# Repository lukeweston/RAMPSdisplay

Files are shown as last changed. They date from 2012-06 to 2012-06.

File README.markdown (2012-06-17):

v1.1: No SD card or thermocouples. Very simple, low-density, "agricultural" PCB layout, which can easily be made single-sided and is well suited to DIY PCB fabrication. Even inexperienced persons should be able to easily make a working board, using photolithography, toner transfer, or CNC milling techniques.

v1.2: "Official" production version. Includes three thermocouple interfaces and micro-SD card. Micro-SD card socket is the Amphenol 101-00660-68-6.

v1.3: Changed to the same micro-SD card PCB footprint as the Kliment SDRamps board, using some generic micro-SD card socket from eBay.
Also changed to self-oscillating through-hole buzzer, removed buzzer drive oscillator, and reduced prototyping hole number to keep total drill hits less than 300.

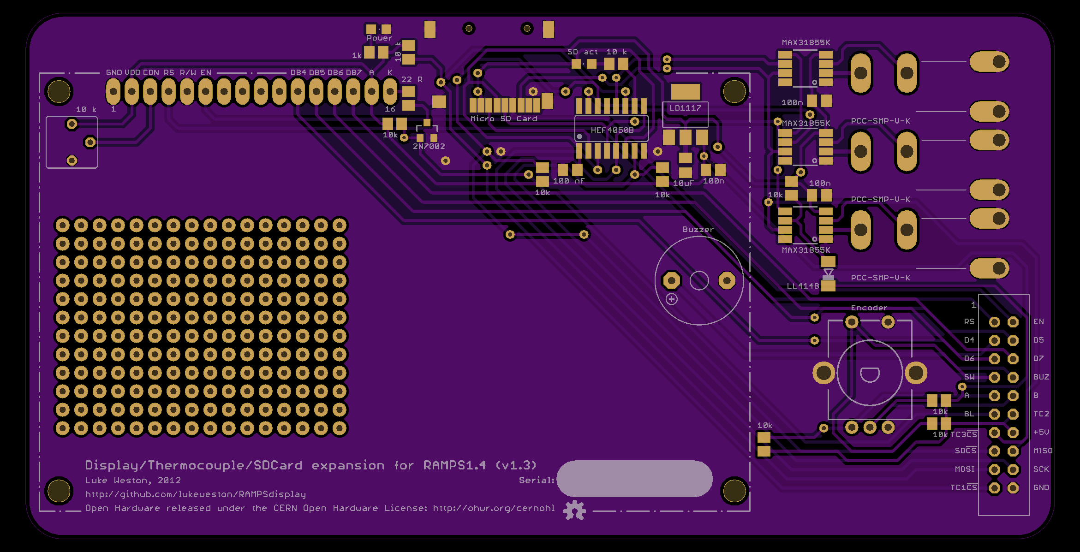
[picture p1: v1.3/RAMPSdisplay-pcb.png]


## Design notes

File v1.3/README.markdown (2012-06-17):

v1.3: Changed to the same micro-SD card PCB footprint as the Kliment SDRamps board, using some generic micro-SD card socket from eBay.
Also changed to self-oscillating through-hole buzzer, removed buzzer drive oscillator, and reduced prototyping hole number to keep total drill hits less than 300.

Pinout: The pinout takes the 20-way cable from the display board (IDC header plug) and splits it in half, with 13 wires going to 13 contiguous pins on the 18-way single-row
expansion header on the edge of the RAMPS board, and 7 wires going to an 8-pin dual-row IDC header plug which connects to the SPI header. So you can just take a 13-way
single-row 0.1" IDC ribbon cable header plug and a 8-pin dual-row 0.1" IDC ribbon cable header plug and just crimp them on and plug them straight on without any crossovers or
the like.

Note that the 8th pin on the SPI header plug is not connected to the cable.

This is the pinout for the 20-pin (dual-row) IDC ribbon cable header on the display board:

1: RS (Pin 18 on 18-pin RAMPS expansion header, Arduino pin 16)  
2: EN (Pin 17 on 18-pin RAMPS expansion header, Arduino pin 17)  
3: D4 (Pin 16 on 18-pin RAMPS expansion header, Arduino pin 23)  
4: D5 (Pin 15 on 18-pin RAMPS expansion header, Arduino pin 25)  
5: D6 (Pin 14 on 18-pin RAMPS expansion header, Arduino pin 27)  
6: D7 (Pin 13 on 18-pin RAMPS expansion header, Arduino pin 29)  
7: Sw (Pin 12 on 18-pin RAMPS expansion header, Arduino pin 31)  
8: Buzzer (Pin 11 on 18-pin RAMPS expansion header, Arduino pin 33)  
9: Encoder A (Pin 10 on 18-pin RAMPS expansion header, Arduino pin 35)  
10: Encoder B (Pin 9 on 18-pin RAMPS expansion header, Arduino pin 37)  
11: Backlight (Pin 8 on 18-pin RAMPS expansion header, Arduino pin 38)  
12: TC2 (Pin 7 on 18-pin RAMPS expansion header, Arduino pin 41)  
13: TC3 (Pin 6 on 18-pin RAMPS expansion header, Arduino pin 43)  

14: +5V (Pin 1 on RAMPS 8-pin SPI header, 8x2 IDC header plug)  
15: SD CS (Pin 2 on RAMPS SPI header, Arduino pin 49)  
16: MISO (Pin 3 on RAMPS SPI header, Arduino pin 50)  
17: MOSI (Pin 4 on RAMPS SPI header, Arduino pin 51)  
18: SCK (Pin 5 on RAMPS SPI header, Arduino pin 52)  
19: TC1 CS (Pin 6 on RAMPS SPI header, Arduino pin 53)  
20: Gnd (Pin 7 on RAMPS SPI header)

(Note: Pin 8 on 8-pin IDC header plug is not connected.)



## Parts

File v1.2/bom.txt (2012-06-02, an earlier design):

Partlist

Exported from RAMPSdisplay.brd at 28/05/12 3:36 AM

EAGLE Version 6.2.0 Copyright (c) 1988-2012 CadSoft

Assembly variant: 

Part     Value          Package                                Library               Position (mil)        Orientation

C1       100n           C0805K                                 rcl                   (3675 2025)           R270
C2       10uF           C0805K                                 rcl                   (3575 2025)           R270
C3       100n           C0805K                                 rcl                   (4300 2375)           R0
C4       100n           C0805K                                 rcl                   (4300 1862.5)         R0
C5       100 nF         C0805K                                 rcl                   (2950 1975)           R180
C6       100 nF         C0805K                                 rcl                   (2937.5 1700)         R180
D1       LL4148         SOD80C                                 diode                 (4350 1437.5)         R90
IC1      HEF4050B       SO16                                   40xx                  (3175 2225)           R0
IC2      LD1117         SOT223                                 burr-brown            (3575 2300)           R0
IC3      MAX31855K      MCLENG_SOIC-8                          RAMPSdisplay          (4225 2550)           R180
IC4      MAX31855K      MCLENG_SOIC-8                          RAMPSdisplay          (4225 2125)           R180
IC5      TL331          DBV-R-PDSO-G5                          linear                (3125 1625)           R270
IC6      MAX31855K      MCLENG_SOIC-8                          RAMPSdisplay          (4225 1700)           R180
J1                      CON20                                  con-harting           (5300 725)            R270
J2       PCC-SMP-V-K    MCLAUGHLINENG_TC_JACK                  RAMPSdisplay          (5275 2525)           R90
J3       PCC-SMP-V-K    MCLAUGHLINENG_TC_JACK                  RAMPSdisplay          (5275 2100)           R90
J4       MicroSD Card   ADAFRUIT_MICROSD                       RAMPSdisplay          (2875 2050)           R180
J5       PCC-SMP-V-K    MCLAUGHLINENG_TC_JACK                  RAMPSdisplay          (5275 1675)           R90
LCD1     HD44780 20x4   HDM20416L                              abi-lcd               (1975 1325)           R0
LED1     Power          CHIPLED_0805                           led                   (2187.5 2587.5)       R270
LED2     SD act         CHIPLED_0805                           led                   (3025 2575)           R90
Q1       2N7002         SOT23-3                                freetronics-master-v1 (2175 2287.5)         R0
Q2       Piezo          FREETRONICS-MASTER-V1_BUZZER-12X12-SMT RAMPSdisplay          (3575 1625)           R180
R1       10k            M0805                                  rcl                   (4950 750)            R0
R2       10k            M0805                                  rcl                   (4950 625)            R0
R3       10k            M0805                                  rcl                   (4950 875)            R0
R4       22 R           M0805                                  rcl                   (2137.5 2425)         R180
R5       10k            M0805                                  rcl                   (2000 2250)           R180
R6       1k             M0805                                  rcl                   (2012.5 2587.5)       R180
R7       10 k           M0805                                  rcl                   (3200 2575)           R0
R8       10k            M0805                                  rcl                   (2937.5 1425)         R180
R9       10 k           M0805                                  rcl                   (4975 1287.5)         R270
R10      10k            M0805                                  rcl                   (3425 2000)           R0
R11      10k            M0805                                  rcl                   (3125 1475)           R0
R12      3.3k           M0805                                  rcl                   (3125 1775)           R0
R13      10k            M0805                                  rcl                   (2937.5 1550)         R180
R14      10 k           M0805                                  rcl                   (4150 1900)           R90
SW1      CI-11          CI-11                                  piher                 (4575 900)            R0
VR1      10 k           CT6                                    pot                   (250 2150)            R90

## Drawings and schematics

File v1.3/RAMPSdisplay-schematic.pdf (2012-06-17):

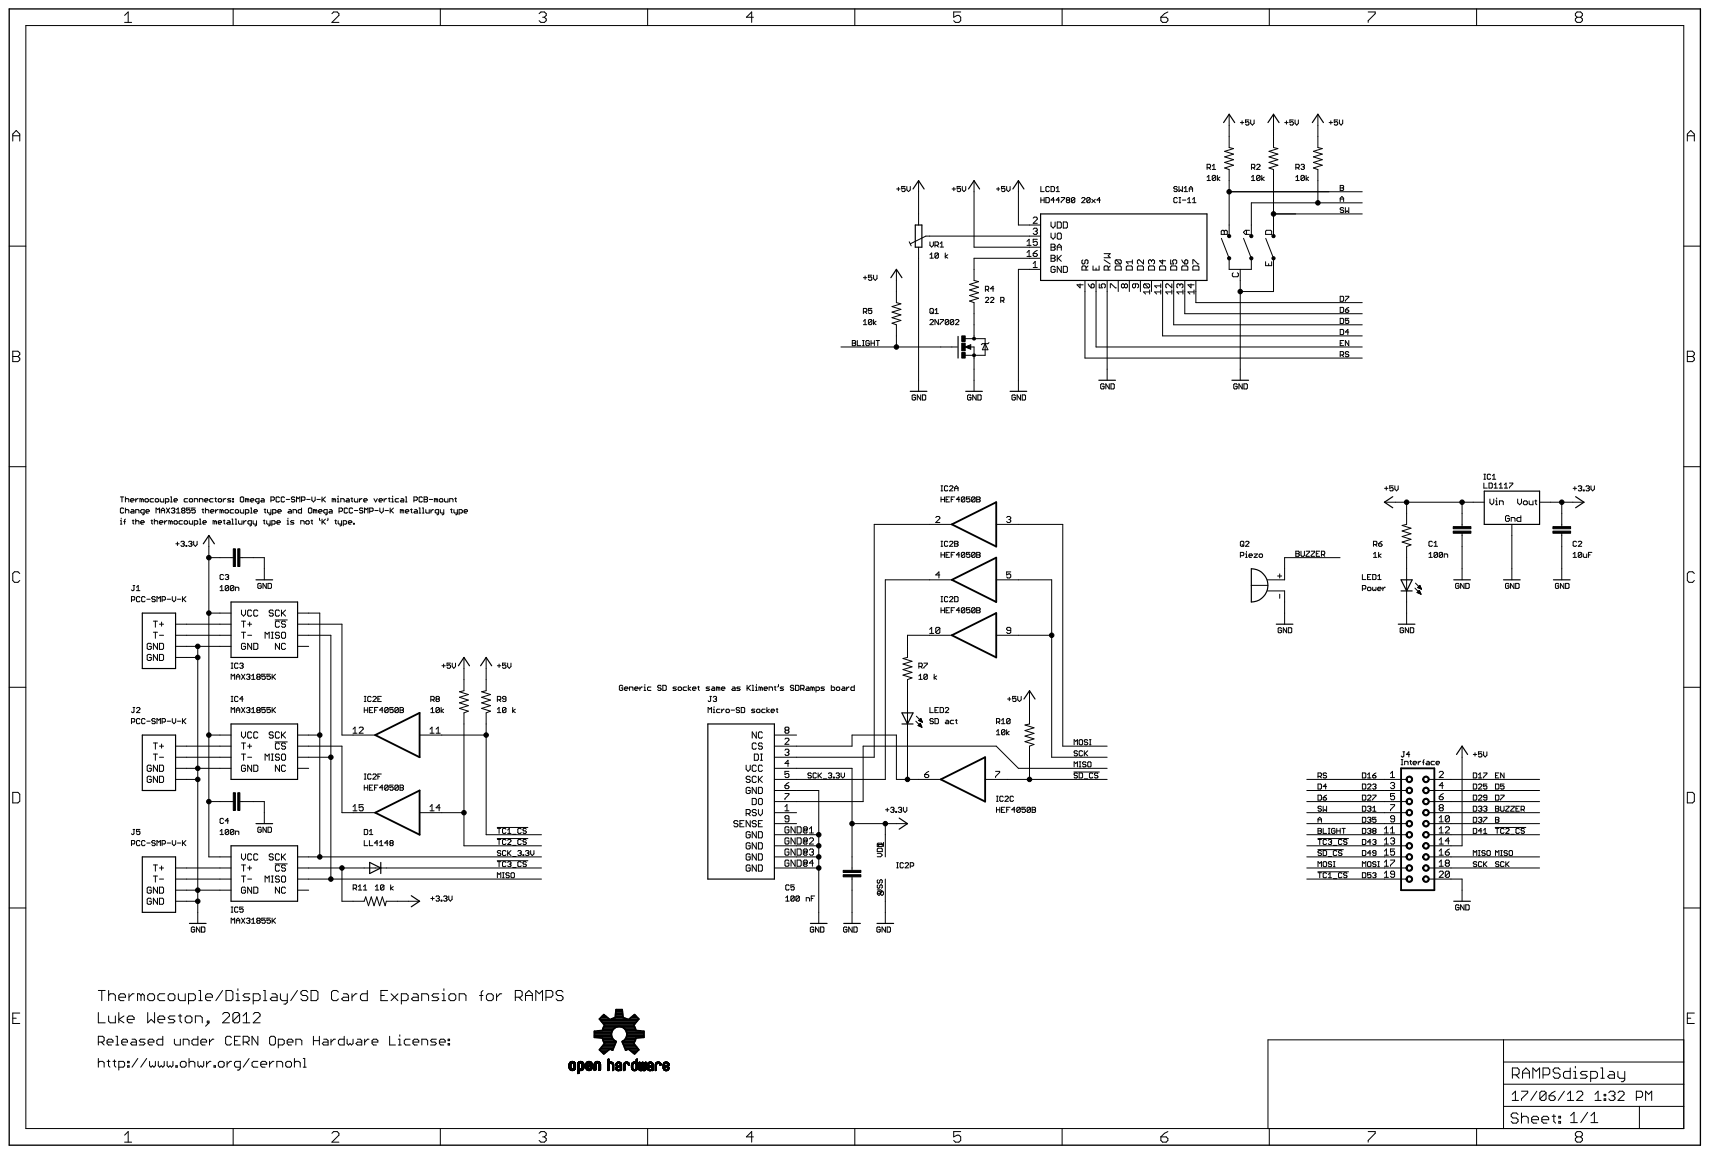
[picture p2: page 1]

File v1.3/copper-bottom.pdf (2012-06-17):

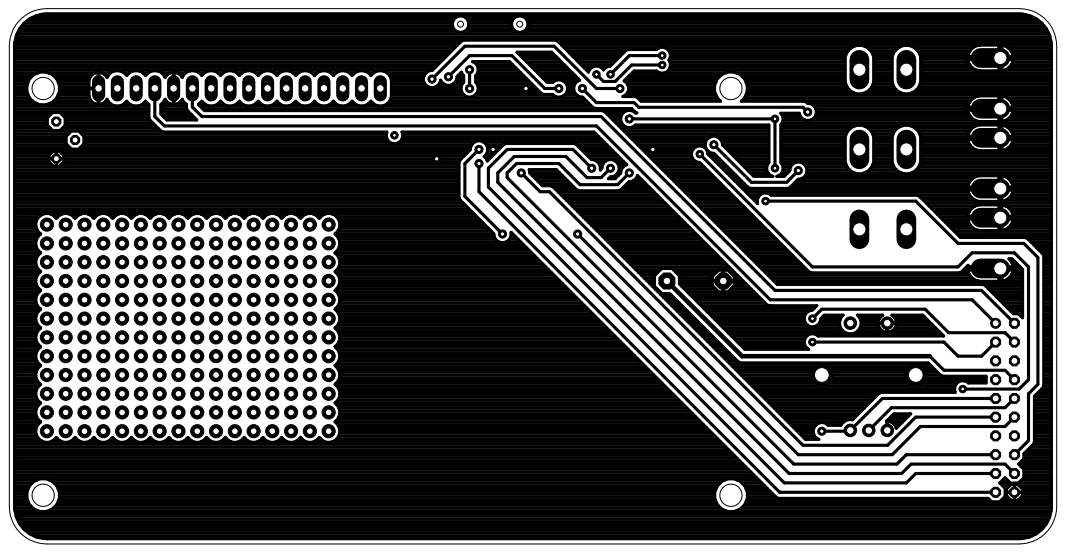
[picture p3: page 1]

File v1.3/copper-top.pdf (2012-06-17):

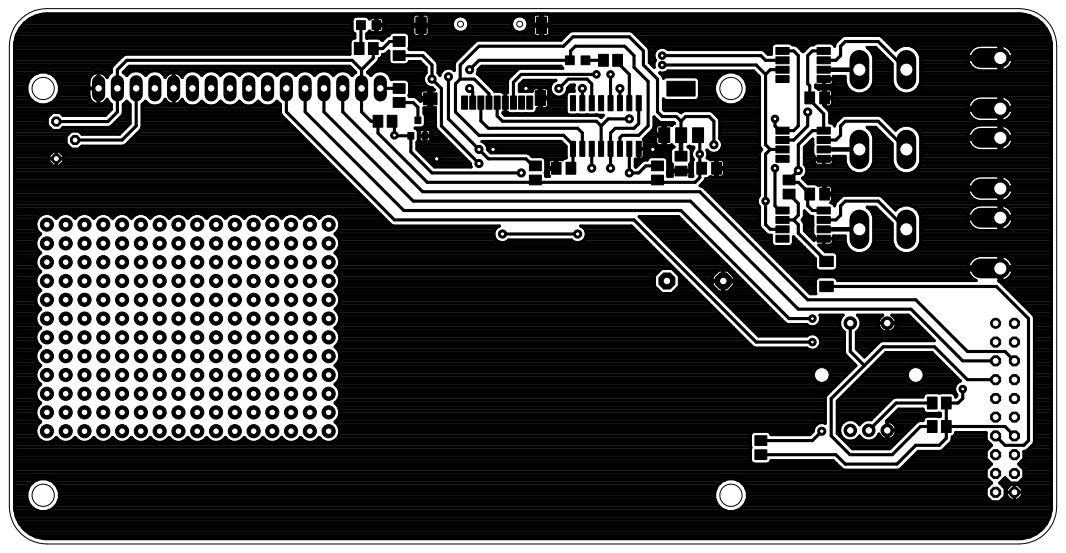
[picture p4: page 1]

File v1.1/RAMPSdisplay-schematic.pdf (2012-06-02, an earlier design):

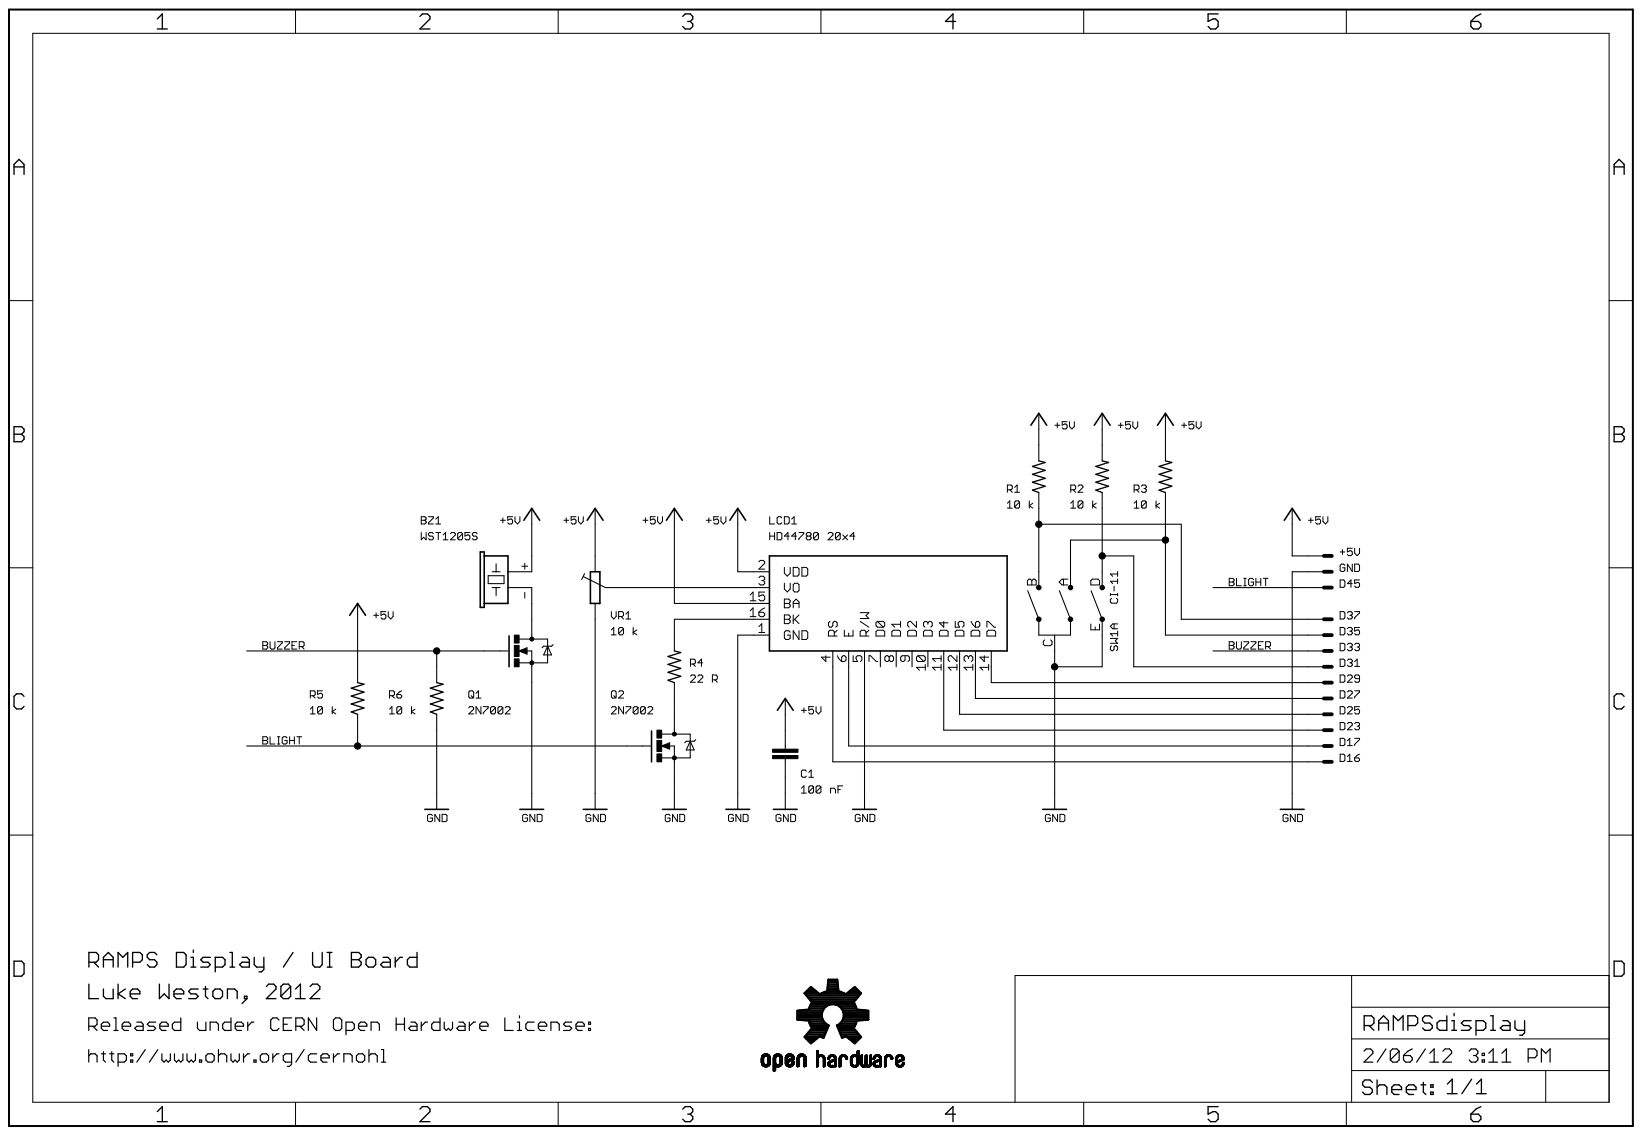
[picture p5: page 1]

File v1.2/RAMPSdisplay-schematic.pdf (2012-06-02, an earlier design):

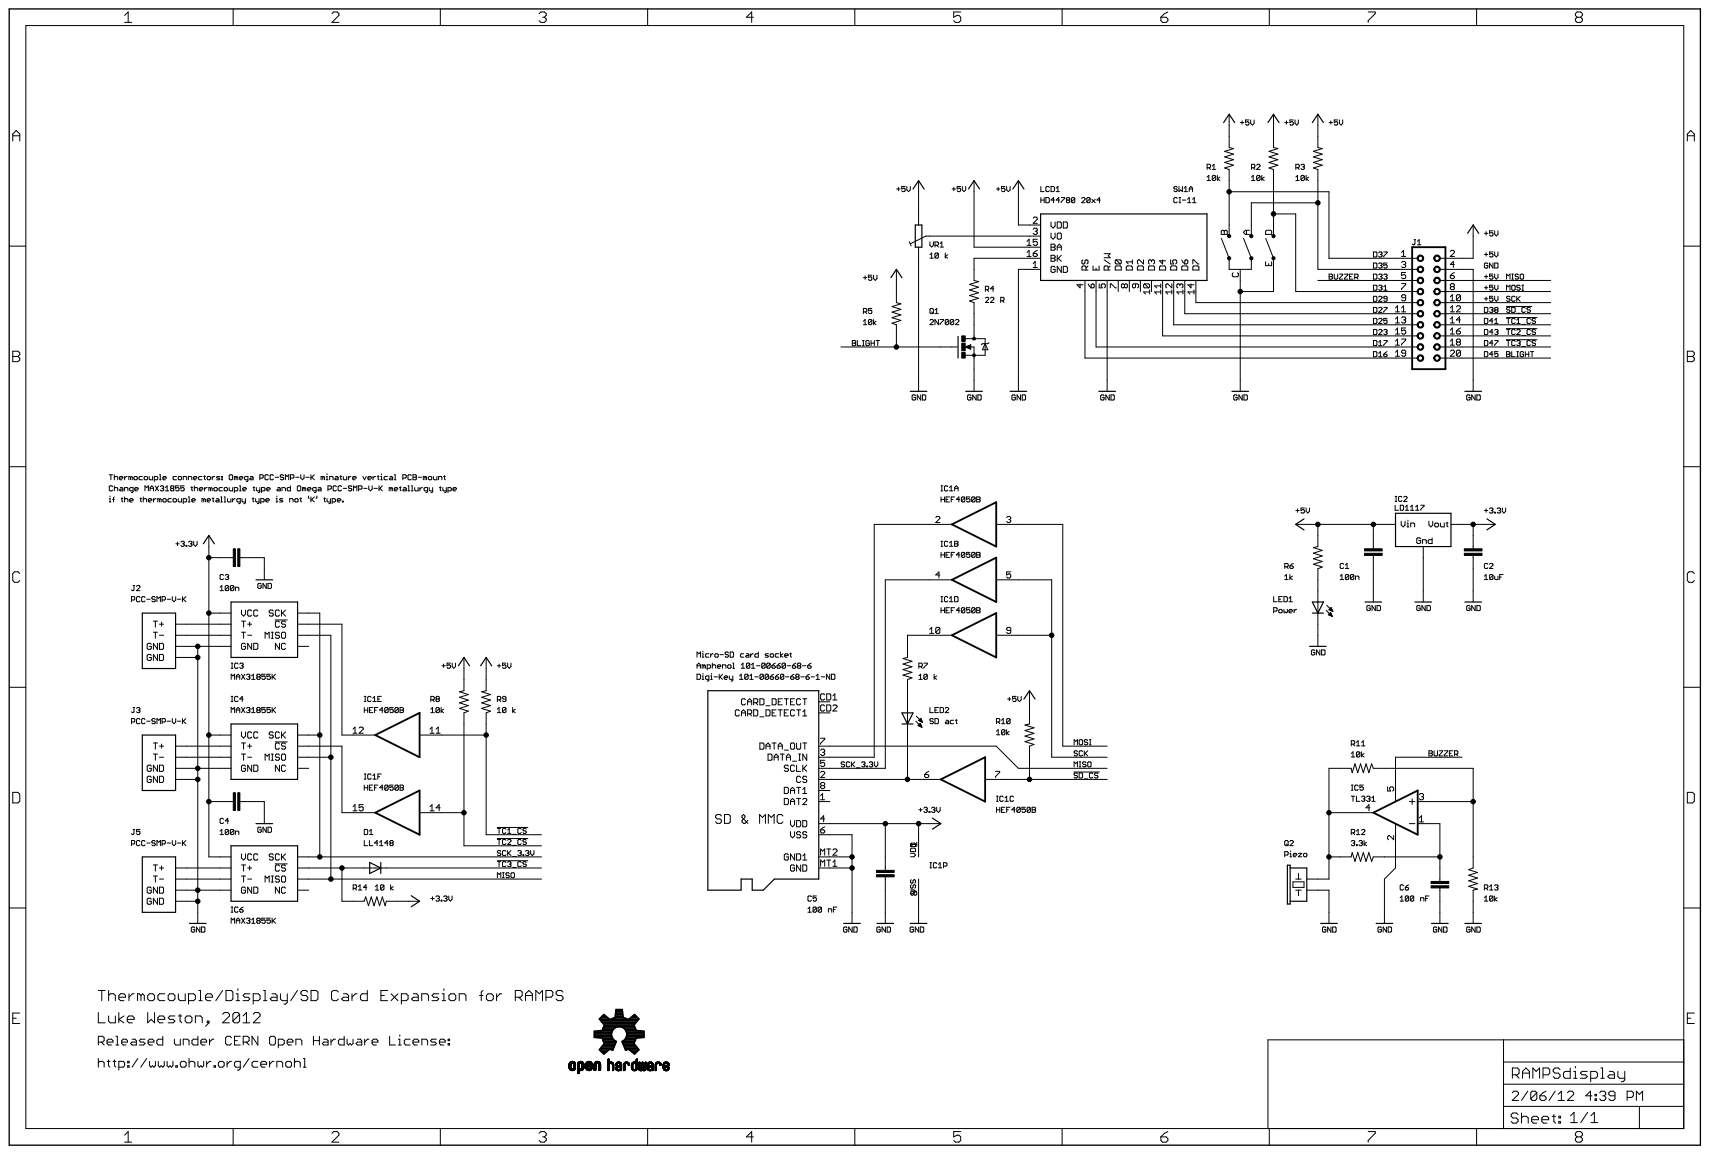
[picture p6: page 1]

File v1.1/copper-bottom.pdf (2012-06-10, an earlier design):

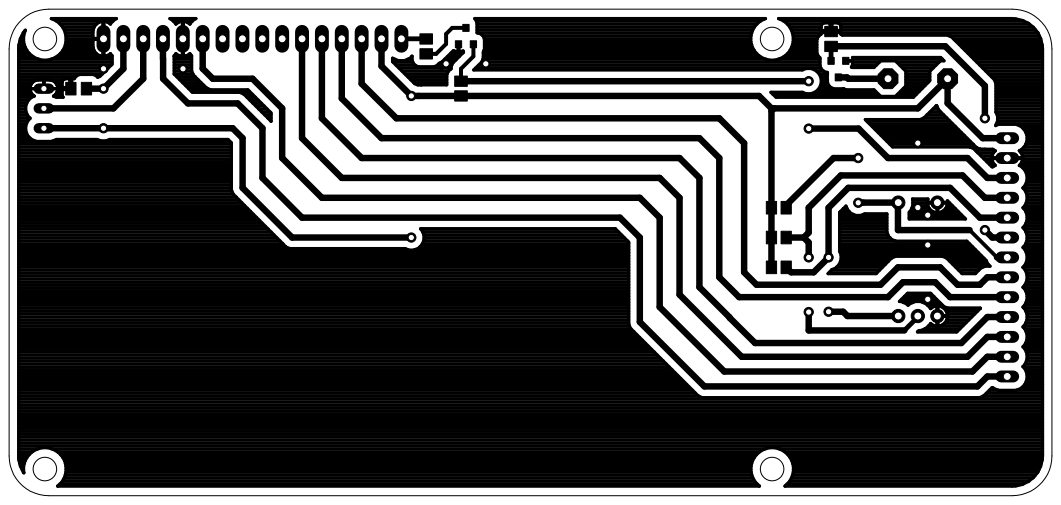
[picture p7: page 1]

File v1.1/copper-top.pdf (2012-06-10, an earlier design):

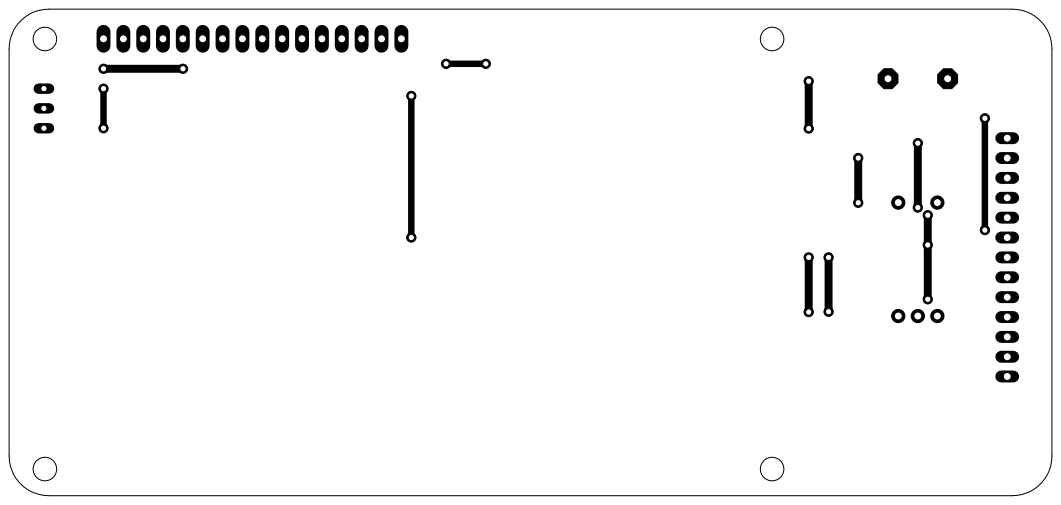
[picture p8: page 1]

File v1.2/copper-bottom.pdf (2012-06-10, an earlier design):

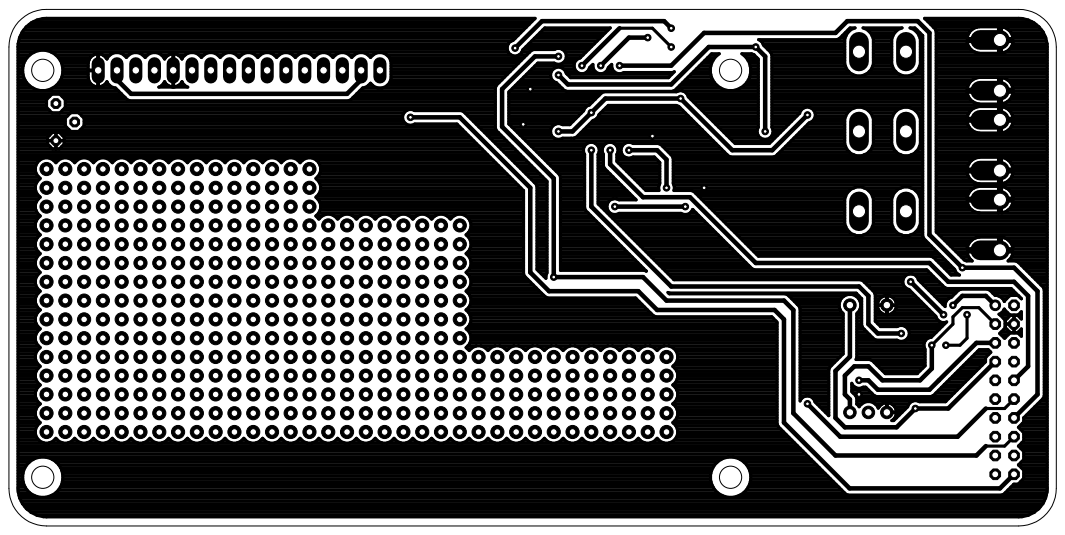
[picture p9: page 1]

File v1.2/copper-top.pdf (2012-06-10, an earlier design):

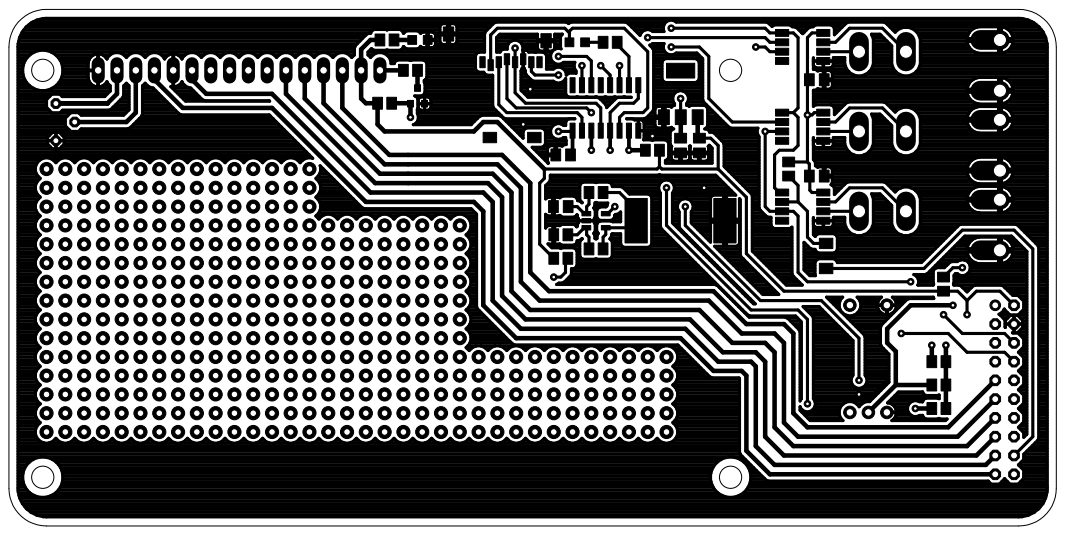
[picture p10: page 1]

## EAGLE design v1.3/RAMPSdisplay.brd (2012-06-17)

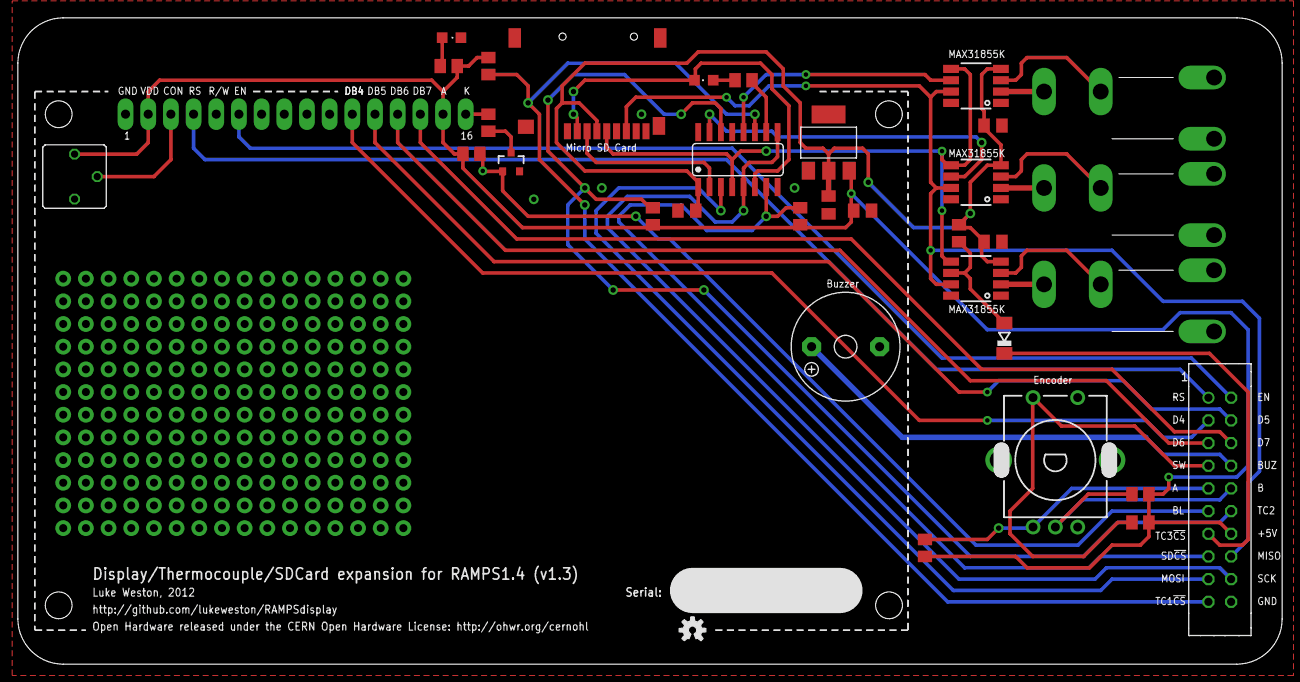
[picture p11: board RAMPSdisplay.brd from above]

Board: 2 copper layers, 141.6 x 72.4 mm, 35 parts (0 on the bottom side), 39 nets.

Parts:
C1, C3, C4: 100n; C0805K
C2: 10uF; C0805K
C5: 100 nF; C0805K
D1: LL4148; SOD80C
IC1: LD1117; SOT223
IC2: HEF4050B; SO16
IC3, IC4, IC5: MAX31855K; MCLENG_SOIC-8
J1, J2, J5: PCC-SMP-V-K; MCLAUGHLINENG_TC_JACK
J3: Micro-SD socket; MICROSD_PP
J4: Interface; CON20
LCD1: HD44780 20x4; HDM20416L
LED1: Power; CHIPLED_0805
LED2: SD act; CHIPLED_0805
Q1: 2N7002; SOT23-3
Q2: Piezo; F/TMB
R1, R2, R3, R5, R8, R10: 10k; M0805
R4: 22 R; M0805
R6: 1k; M0805
R7, R9, R11: 10 k; M0805
SW1: CI-11
U$: OSHW-LOGOS; OSHW-LOGO-S
VR1: 10 k; CT6

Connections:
!SD_CS: IC2.7, J4.15, R10.1
!TC1_CS: IC2.11, J4.19, R9.1
!TC2_CS: IC2.14, J4.12, R8.1
!TC3_CS: D1.C, J4.13
+3V3: C2.1, C3.1, C4.1, C5.1, IC1.2, IC2.1, IC3.VCC, IC4.VCC, IC5.VCC, J3.4, R11.2
+5V: C1.1, IC1.3, J4.14, LCD1.2, LCD1.15, R1.2, R2.2, R3.2, R5.2, R6.2, R8.2, R9.2, R10.2, VR1.A
A: J4.9, R3.1, SW1.A
B: J4.10, R1.1, SW1.B
BF: IC2.12, IC3.CS
BLIGHT: J4.11, Q1.1, R5.1
BUZZER: J4.8, Q2.+
D4: J4.3, LCD1.11
D5: J4.4, LCD1.12
D6: J4.5, LCD1.13
D7: J4.6, LCD1.14
EN: J4.2, LCD1.6
FOO: IC2.6, J3.2, LED2.C
GND: C1.2, C2.2, C3.2, C4.2, C5.2, IC1.1, IC2.8, IC3.GND, IC4.GND, IC5.GND, J1.P$1, J1.P$2, J2.P$1, J2.P$2, J3.6, J3.GND@1, J3.GND@2, J3.GND@3, J3.GND@4, J4.20, J5.P$1, J5.P$2, LCD1.1, LCD1.5, LED1.C, Q1.2, Q2.-, SW1.C, SW1.E, VR1.E
MISO: IC3.SO, IC4.SO, IC5.SO, J3.7, J4.16
MOSI: IC2.3, J4.17
MOSI_3.3V: IC2.2, J3.3
unnamed: LCD1.3, VR1.S
unnamed: LCD1.16, R4.2
unnamed: IC5.T+, J5.T+
unnamed: IC5.T-, J5.T-
unnamed: Q1.3, R4.1
unnamed: IC4.T-, J2.T-
unnamed: D1.A, IC5.CS, R11.1
unnamed: IC4.T+, J2.T+
unnamed: IC3.T-, J1.T-
unnamed: IC3.T+, J1.T+
unnamed: IC2.15, IC4.CS
unnamed: LED2.A, R7.1
unnamed: IC2.10, R7.2
unnamed: LED1.A, R6.1
RS: J4.1, LCD1.4
SCK: IC2.5, IC2.9, J4.18
SCK_3.3V: IC2.4, IC3.SCK, IC4.SCK, IC5.SCK, J3.5
SW: J4.7, R2.1, SW1.D

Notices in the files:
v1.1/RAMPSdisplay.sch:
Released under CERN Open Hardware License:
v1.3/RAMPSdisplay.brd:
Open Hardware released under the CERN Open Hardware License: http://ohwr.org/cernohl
